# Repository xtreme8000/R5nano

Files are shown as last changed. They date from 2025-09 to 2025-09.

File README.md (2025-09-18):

# R5 nano

Single board computer with future Linux support, mostly intended for use as a lightweight server.

Planned SoC implementation using LiteX featuring a RISC-V CPU and 64MiB RAM.

## Gateware

TODO

## Software

Work in progress.

Firmware supports bitstream upload over USB to the FPGA at the moment.

## Hardware

* iCE40UP5k FPGA, 5280 LUTs
* 64MiB SD-RAM
* microSD card for storage
* USB port for connectivity like ethernet
* USB-C port for power, bitstream upload
* STM32F103 for initial bitstream load from either USB-C or microSD
* Debug header with FPGA+STM32 GPIO, SWD for STM32
* 52x52mm (~2x2in) board

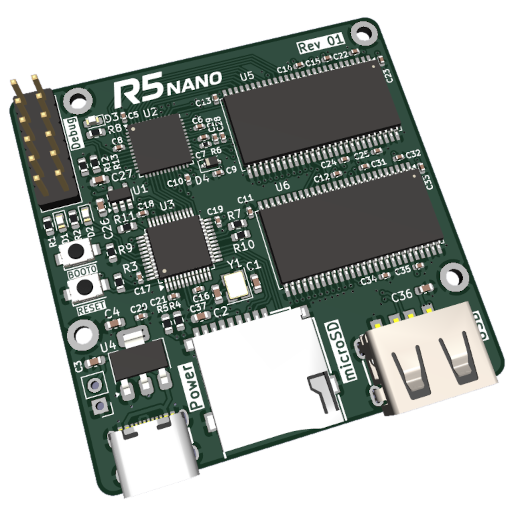
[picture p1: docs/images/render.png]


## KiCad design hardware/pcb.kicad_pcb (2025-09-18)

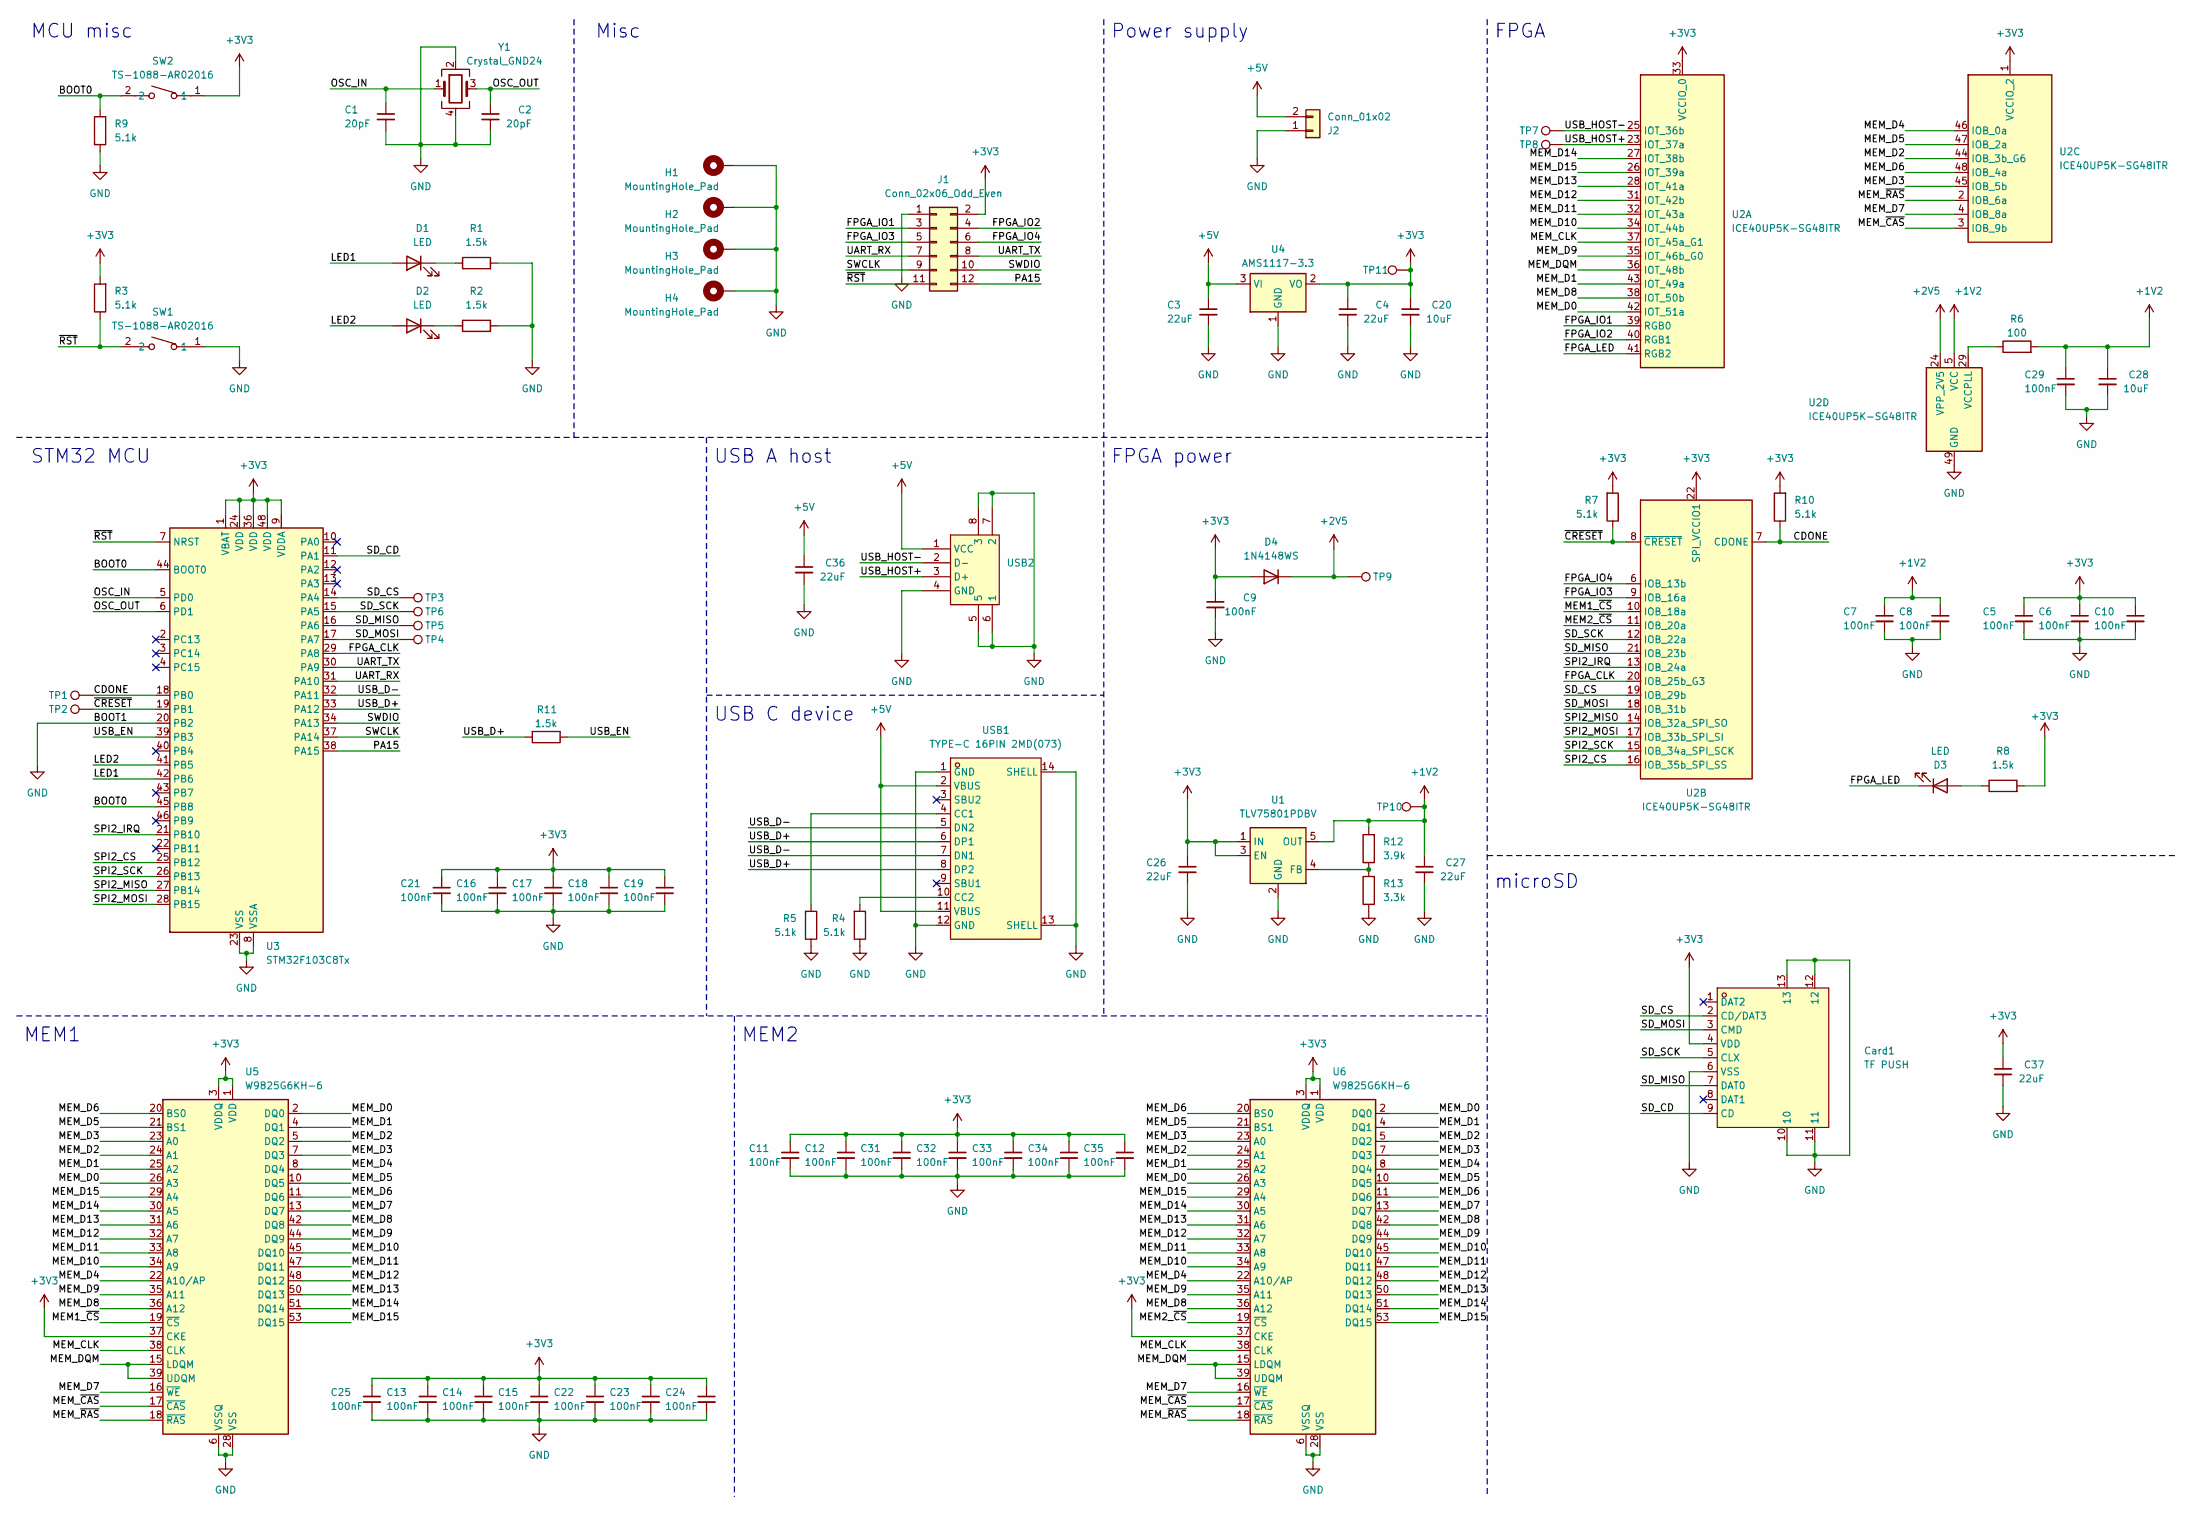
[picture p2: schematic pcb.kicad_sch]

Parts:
C1, C2: 20pF; C_0603_1608Metric; LCSC Part C1648
C3, C4, C26, C27, C36, C37: 22uF; C_0603_1608Metric; LCSC Part C59461
C5, C6, C7, C8, C9, C10, C11, C12, C13, C14, C15, C16, C17, C18, C19, C21, C22, C23, C24, C25, C29, C31, C32, C33, C34, C35: 100nF; C_0402_1005Metric; LCSC Part C1525
C20, C28: 10uF; C_0402_1005Metric; LCSC Part C15525
Card1: TF PUSH; TF-SMD_TF-PUSH; LCSC Part C393941
D1, D2, D3: LED; LED_0603_1608Metric; LCSC Part C2286
D4: 1N4148WS; D_SOD-323; LCSC Part C2128
H1, H2, H3, H4: MountingHole_Pad; MountingHole_2.2mm_M2_DIN965_Pad
J1: Conn_02x06_Odd_Even; PinHeader_2x06_P2.54mm_Vertical
J2: Conn_01x02; PinHeader_1x02_P2.54mm_Vertical
R1, R2, R8, R11: 1.5k; R_0603_1608Metric; LCSC Part C22843
R3, R4, R5, R7, R9, R10: 5.1k; R_0603_1608Metric; LCSC Part C23186
R6: 100; R_0402_1005Metric; LCSC Part C25076
R12: 3.9k; R_0603_1608Metric; LCSC Part C23018
R13: 3.3k; R_0603_1608Metric; LCSC Part C22978
SW1, SW2: TS-1088-AR02016; SW-SMD_L3.9-W3.0-P4.45; LCSC Part C720477
TP1, TP2, TP3, TP4, TP5, TP6, TP7, TP8, TP9, TP10, TP11: TestPoint; TestPoint_Pad_D2.0mm
U1: TLV75801PDBV; SOT-23-5; LCSC Part C2877852
U2: ICE40UP5K-SG48ITR; QFN-48-1EP_7x7mm_P0.5mm_EP5.6x5.6mm; LCSC Part C2678152
U3: STM32F103C8Tx; LQFP-48_7x7mm_P0.5mm; LCSC Part C8734
U4: AMS1117-3.3; SOT-223-3_TabPin2; LCSC Part C6186
U5, U6: W9825G6KH-6; TSOP-II-54_22.2x10.16mm_P0.8mm; LCSC Part C62246
USB1: TYPE-C 16PIN 2MD(073); USB-C-SMD_TYPE-C-6PIN-2MD-073; LCSC Part C2765186
USB2: USB-A-SMD_USB-M-21; LCSC Part C42474
Y1: Crystal_GND24; Crystal_SMD_3225-4Pin_3.2x2.5mm; LCSC Part C9002

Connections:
+1V2: C7.1, C8.1, C27.1, C28.1, C29.1, R6.2, R12.2, TP10.1, U1.5 (OUT), U2.5 (VCC), U2.30 (VCC)
+2V5: D4.1 (K), TP9.1, U2.24 (VPP_2V5)
+3V3: C4.1, C5.1, C6.1, C9.1, C10.1, C11.1, C12.1, C13.1, C14.1, C15.1, C16.1, C17.1, C18.1, C19.1, C20.1, C21.1, C22.1, C23.1, C24.1, C25.1, C26.1, C31.1, C32.1, C33.1, C34.1, C35.1, C37.1, Card1.4 (VDD), D4.2 (A), J1.2, R3.2, R7.2, R8.2, R10.2, SW2.1, TP11.1, U1.1 (IN), U1.3 (EN), U2.1 (VCCIO_2), U2.22 (SPI_VCCIO1), U2.33 (VCCIO_0), U3.1 (VBAT), U3.9 (VDDA), U3.24 (VDD), U3.36 (VDD), U3.48 (VDD), U4.2 (VO), U5.1 (VDD), U5.3 (VDDQ), U5.9 (VDDQ), U5.14 (VDD), U5.27 (VDD), U5.37 (CKE), U5.43 (VDDQ), U5.49 (VDDQ), U6.1 (VDD), U6.3 (VDDQ), U6.9 (VDDQ), U6.14 (VDD), U6.27 (VDD), U6.37 (CKE), U6.43 (VDDQ), U6.49 (VDDQ)
+5V: C3.1, C36.1, J2.2, U4.3 (VI), USB1.2 (VBUS), USB1.11 (VBUS), USB2.1 (VCC)
/BOOT0: R9.2, SW2.2, U3.44 (BOOT0), U3.45 (PB8)
/CDONE: R10.1, TP1.1, U2.7 (CDONE), U3.18 (PB0)
/FPGA_CLK: U2.20 (IOB_25b_G3), U3.29 (PA8)
/FPGA_IO1: J1.3, U2.39 (RGB0)
/FPGA_IO2: J1.4, U2.40 (RGB1)
/FPGA_IO3: J1.5, U2.9 (IOB_16a)
/FPGA_IO4: J1.6, U2.6 (IOB_13b)
/FPGA_LED: D3.1 (K), U2.41 (RGB2)
/LED1: D1.2 (A), U3.42 (PB6)
/LED2: D2.2 (A), U3.41 (PB5)
/MEM1_~CS: U2.10 (IOB_18a), U5.19 (~CS)
/MEM2_~CS: U2.11 (IOB_20a), U6.19 (~CS)
/MEM_CLK: U2.37 (IOT_45a_G1), U5.38 (CLK), U6.38 (CLK)
/MEM_D0: U2.42 (IOT_51a), U5.2 (DQ0), U5.26 (A3), U6.2 (DQ0), U6.26 (A3)
/MEM_D1: U2.43 (IOT_49a), U5.4 (DQ1), U5.25 (A2), U6.4 (DQ1), U6.25 (A2)
/MEM_D2: U2.44 (IOB_3b_G6), U5.5 (DQ2), U5.24 (A1), U6.5 (DQ2), U6.24 (A1)
/MEM_D3: U2.45 (IOB_5b), U5.7 (DQ3), U5.23 (A0), U6.7 (DQ3), U6.23 (A0)
/MEM_D4: U2.46 (IOB_0a), U5.8 (DQ4), U5.22 (A10/AP), U6.8 (DQ4), U6.22 (A10/AP)
/MEM_D5: U2.47 (IOB_2a), U5.10 (DQ5), U5.21 (BS1), U6.10 (DQ5), U6.21 (BS1)
/MEM_D6: U2.48 (IOB_4a), U5.11 (DQ6), U5.20 (BS0), U6.11 (DQ6), U6.20 (BS0)
/MEM_D7: U2.4 (IOB_8a), U5.13 (DQ7), U5.16 (~WE), U6.13 (DQ7), U6.16 (~WE)
/MEM_D8: U2.38 (IOT_50b), U5.36 (A12), U5.42 (DQ8), U6.36 (A12), U6.42 (DQ8)
/MEM_D9: U2.35 (IOT_46b_G0), U5.35 (A11), U5.44 (DQ9), U6.35 (A11), U6.44 (DQ9)
/MEM_D10: U2.34 (IOT_44b), U5.34 (A9), U5.45 (DQ10), U6.34 (A9), U6.45 (DQ10)
/MEM_D11: U2.32 (IOT_43a), U5.33 (A8), U5.47 (DQ11), U6.33 (A8), U6.47 (DQ11)
/MEM_D12: U2.31 (IOT_42b), U5.32 (A7), U5.48 (DQ12), U6.32 (A7), U6.48 (DQ12)
/MEM_D13: U2.28 (IOT_41a), U5.31 (A6), U5.50 (DQ13), U6.31 (A6), U6.50 (DQ13)
/MEM_D14: U2.27 (IOT_38b), U5.30 (A5), U5.51 (DQ14), U6.30 (A5), U6.51 (DQ14)
/MEM_D15: U2.26 (IOT_39a), U5.29 (A4), U5.53 (DQ15), U6.29 (A4), U6.53 (DQ15)
/MEM_DQM: U2.36 (IOT_48b), U5.15 (LDQM), U5.39 (UDQM), U6.15 (LDQM), U6.39 (UDQM)
/MEM_~CAS: U2.3 (IOB_9b), U5.17 (~CAS), U6.17 (~CAS)
/MEM_~RAS: U2.2 (IOB_6a), U5.18 (~RAS), U6.18 (~RAS)
/OSC_IN: C1.1, U3.5 (PD0), Y1.1
/OSC_OUT: C2.1, U3.6 (PD1), Y1.3
/PA15: J1.12, U3.38 (PA15)
/SD_CD: Card1.9 (CD), U3.11 (PA1)
/SD_CS: Card1.2 (CD/DAT3), TP3.1, U2.19 (IOB_29b), U3.14 (PA4)
/SD_MISO: Card1.7 (DAT0), TP5.1, U2.21 (IOB_23b), U3.16 (PA6)
/SD_MOSI: Card1.3 (CMD), TP4.1, U2.18 (IOB_31b), U3.17 (PA7)
/SD_SCK: Card1.5 (CLX), TP6.1, U2.12 (IOB_22a), U3.15 (PA5)
/SPI2_CS: U2.16 (IOB_35b_SPI_SS), U3.25 (PB12)
/SPI2_IRQ: U2.13 (IOB_24a), U3.21 (PB10)
/SPI2_MISO: U2.14 (IOB_32a_SPI_SO), U3.27 (PB14)
/SPI2_MOSI: U2.17 (IOB_33b_SPI_SI), U3.28 (PB15)
/SPI2_SCK: U2.15 (IOB_34a_SPI_SCK), U3.26 (PB13)
/SWCLK: J1.9, U3.37 (PA14)
/SWDIO: J1.10, U3.34 (PA13)
/UART_RX: J1.7, U3.31 (PA10)
/UART_TX: J1.8, U3.30 (PA9)
/USB_D+: R11.2, U3.33 (PA12), USB1.6 (DP1), USB1.8 (DP2)
/USB_D-: U3.32 (PA11), USB1.5 (DN2), USB1.7 (DN1)
/USB_EN: R11.1, U3.39 (PB3)
/USB_HOST+: TP8.1, U2.23 (IOT_37a), USB2.3 (D+)
/USB_HOST-: TP7.1, U2.25 (IOT_36b), USB2.2 (D-)
/~CRESET: R7.1, TP2.1, U2.8 (~CRESET), U3.19 (PB1)
/~RST: J1.11, R3.1, SW1.2, U3.7 (NRST)
GND: C1.2, C2.2, C3.2, C4.2, C5.2, C6.2, C7.2, C8.2, C9.2, C10.2, C11.2, C12.2, C13.2, C14.2, C15.2, C16.2, C17.2, C18.2, C19.2, C20.2, C21.2, C22.2, C23.2, C24.2, C25.2, C26.2, C27.2, C28.2, C29.2, C31.2, C32.2, C33.2, C34.2, C35.2, C36.2, C37.2, Card1.6 (VSS), Card1.10, Card1.11, Card1.12, Card1.13, H1.1, H2.1, H3.1, H4.1, J1.1, J2.1, R1.2, R2.2, R4.1, R5.1, R9.1, R13.1, SW1.1, U1.2 (GND), U2.49 (GND), U3.8 (VSSA), U3.20 (PB2), U3.23 (VSS), U3.35 (VSS), U3.47 (VSS), U4.1 (GND), U5.6 (VSSQ), U5.12 (VSSQ), U5.28 (VSS), U5.41 (VSS), U5.46 (VSSQ), U5.52 (VSSQ), U5.54 (VSS), U6.6 (VSSQ), U6.12 (VSSQ), U6.28 (VSS), U6.41 (VSS), U6.46 (VSSQ), U6.52 (VSSQ), U6.54 (VSS), USB1.1 (GND), USB1.12 (GND), USB1.13 (SHELL), USB1.14 (SHELL), USB2.4 (GND), USB2.5, USB2.6 (1), USB2.7 (2), USB2.8 (3), Y1.2, Y1.4
unnamed: D1.1 (K), R1.1
unnamed: D2.1 (K), R2.1
unnamed: D3.2 (A), R8.1
unnamed: R12.1, R13.2, U1.4 (FB)
unnamed: R6.1, U2.29 (VCCPLL)
unnamed: R5.2, USB1.4 (CC1)
unnamed: R4.2, USB1.10 (CC2)

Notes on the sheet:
microSD
MEM1
Misc
STM32 MCU
USB A host
MCU misc
MEM2
USB C device
Power supply
FPGA power
FPGA

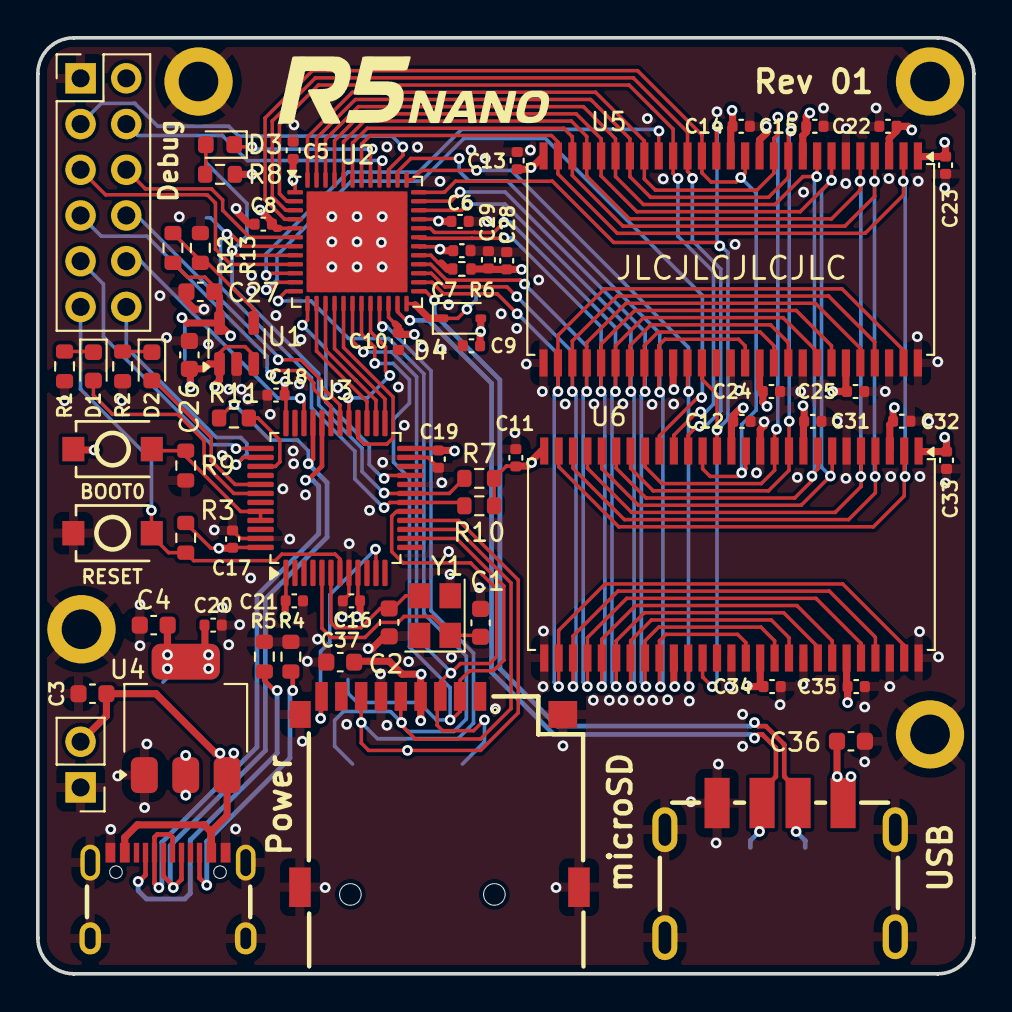
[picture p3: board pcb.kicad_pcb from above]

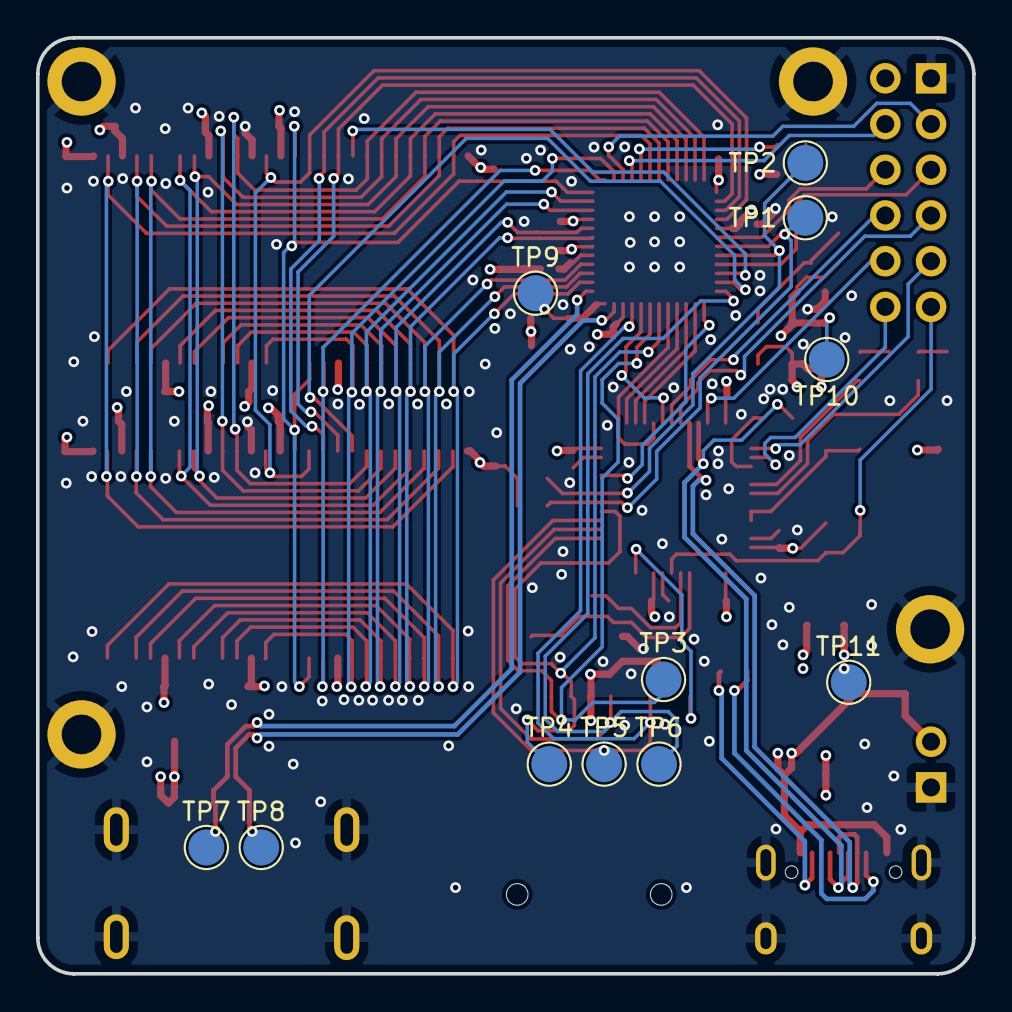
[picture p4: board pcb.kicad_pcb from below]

Board: 4 copper layers, 52.0 x 52.0 mm, 82 parts (11 on the bottom side), 68 nets.

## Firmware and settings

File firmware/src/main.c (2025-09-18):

#ifndef STM32F1
#define STM32F1
#endif

#include <stdio.h>
#include <stdlib.h>
#include <string.h>

#include <libopencm3/cm3/nvic.h>
#include <libopencm3/cm3/systick.h>
#include <libopencm3/stm32/dma.h>
#include <libopencm3/stm32/gpio.h>
#include <libopencm3/stm32/rcc.h>
#include <libopencm3/stm32/spi.h>
#include <libopencm3/stm32/usart.h>
#include <libopencm3/usb/usbd.h>

#include <FreeRTOS.h>
#include <queue.h>
#include <semphr.h>
#include <task.h>

#define PORT_CRESET_B GPIOB
#define PIN_CRESET_B GPIO1

#define PORT_SPI_SS GPIOB
#define PIN_SPI_SS GPIO12

#define PORT_CDONE GPIOB
#define PIN_CDONE GPIO0

#define PORT_USB_EN GPIOB
#define PIN_USB_EN GPIO3

#define PORT_LED1 GPIOB
#define PIN_LED1 GPIO6

#define PORT_LED2 GPIOB
#define PIN_LED2 GPIO5

uint8_t usbd_control_buffer[64]; // buffer for control requests

#define STREAM_PAYLOAD_DATA_SIZE 256

struct stream_payload {
	size_t length;
	uint8_t data[STREAM_PAYLOAD_DATA_SIZE];
};

struct usb_device_descriptor dev_descr = {
	.bLength = USB_DT_DEVICE_SIZE,
	.bDescriptorType = USB_DT_DEVICE,
	.bcdUSB = 0x0200,
	.bDeviceClass = 0,
	.bDeviceSubClass = 0,
	.bDeviceProtocol = 0,
	.bMaxPacketSize0 = 64, // max size
	.idVendor = 0x1209,
	.idProduct = 0x000E,
	.bcdDevice = 0x0100,
	.iManufacturer = 1,
	.iProduct = 2,
	.iSerialNumber = 0,
	.bNumConfigurations = 1,
};

struct usb_endpoint_descriptor usb_endpoints[] = {
	{
		.bLength = USB_DT_ENDPOINT_SIZE,
		.bDescriptorType = USB_DT_ENDPOINT,
		.bEndpointAddress = USB_ENDPOINT_ADDR_OUT(1),
		.bmAttributes = USB_ENDPOINT_ATTR_BULK,
		.wMaxPacketSize = STREAM_PAYLOAD_DATA_SIZE,
	},
	{
		.bLength = USB_DT_ENDPOINT_SIZE,
		.bDescriptorType = USB_DT_ENDPOINT,
		.bEndpointAddress = USB_ENDPOINT_ADDR_IN(2),
		.bmAttributes = USB_ENDPOINT_ATTR_INTERRUPT,
		.wMaxPacketSize = 1,
		.bInterval = 5,
	},
};

struct usb_interface_descriptor usb_iface = {
	.bLength = USB_DT_INTERFACE_SIZE,
	.bDescriptorType = USB_DT_INTERFACE,
	.bInterfaceNumber = 0,
	.bAlternateSetting = 0,
	.bNumEndpoints = 2,
	.bInterfaceClass = USB_CLASS_VENDOR,
	.bInterfaceSubClass = 0,
	.bInterfaceProtocol = 0,
	.iInterface = 0,
	.endpoint = usb_endpoints,
};

struct usb_config_descriptor usb_config = {
	.bLength = USB_DT_CONFIGURATION_SIZE,
	.bDescriptorType = USB_DT_CONFIGURATION,
	.wTotalLength = 0,
	.bNumInterfaces = 1,
	.bConfigurationValue = 1,
	.iConfiguration = 0,
	.bmAttributes = USB_CONFIG_ATTR_DEFAULT,
	.bMaxPower = 100 / 2, // 100mA

	.interface = (struct usb_interface[]) {{
		.num_altsetting = 1,
		.altsetting = &usb_iface,
	}},
};

const char* usb_strings[3] = {
	"xtreme8000",
	"R5nano",
};

QueueHandle_t incoming_data;
QueueHandle_t available_buffers;
QueueHandle_t usb_host_interrupt;

void usb_endpoint_callback(usbd_device* dev, uint8_t ep) {
	if(ep != USB_ENDPOINT_ADDR_OUT(1))
		return;

	struct stream_payload* e;
	xQueueReceive(available_buffers, &e, portMAX_DELAY);
	e->length = usbd_ep_read_packet(dev, ep, e->data, sizeof(e->data));
	xQueueSend(incoming_data, &e, portMAX_DELAY);
}

enum usbd_request_return_codes
usb_creq_callback(usbd_device* dev, struct usb_setup_data* req, uint8_t** buf,
				  uint16_t* len,
				  void (**complete)(usbd_device*, struct usb_setup_data*)) {
	if(req->bmRequestType
	   != (USB_REQ_TYPE_OUT | USB_REQ_TYPE_VENDOR | USB_REQ_TYPE_INTERFACE))
		return USBD_REQ_NOTSUPP;

	switch(req->bRequest) {
		case 10:
			if(req->wLength != 4)
				return USBD_REQ_NOTSUPP;

			uint32_t payload_length = ((*buf)[3] << 24) | ((*buf)[2] << 16)
				| ((*buf)[1] << 8) | (*buf)[0];

			struct stream_payload* e;
			xQueueReceive(available_buffers, &e, portMAX_DELAY);
			e->length = payload_length;
			xQueueSend(incoming_data, &e, portMAX_DELAY);

			return USBD_REQ_HANDLED;
		default: return USBD_REQ_NOTSUPP;
	}
}

static void usb_set_config(usbd_device* dev, uint16_t wValue) {
	usbd_register_control_callback(
		dev, USB_REQ_TYPE_VENDOR | USB_REQ_TYPE_INTERFACE,
		USB_REQ_TYPE_TYPE | USB_REQ_TYPE_RECIPIENT, usb_creq_callback);
	usbd_ep_setup(dev, USB_ENDPOINT_ADDR_OUT(1), USB_ENDPOINT_ATTR_BULK,
				  STREAM_PAYLOAD_DATA_SIZE, usb_endpoint_callback);
	usbd_ep_setup(dev, USB_ENDPOINT_ADDR_IN(2), USB_ENDPOINT_ATTR_INTERRUPT, 1,
				  NULL);
}

void task_usb(void* args) {
	gpio_clear(PORT_USB_EN, PIN_USB_EN);
	vTaskDelay(pdMS_TO_TICKS(100));
	gpio_set(PORT_USB_EN, PIN_USB_EN);

	usbd_device* usbd_dev = usbd_init(
		&st_usbfs_v1_usb_driver, &dev_descr, &usb_config, usb_strings, 2,
		usbd_control_buffer, sizeof(usbd_control_buffer));
	usbd_register_set_config_callback(usbd_dev, usb_set_config);

	while(1) {
		usbd_poll(usbd_dev);

		uint8_t signal;
		if(xQueueReceive(usb_host_interrupt, &signal, 0)) {
			// raise host interrupt
			usbd_ep_write_packet(usbd_dev, USB_ENDPOINT_ADDR_IN(2), &signal,
								 sizeof(signal));
		}
	}
}

void task_blink(void* args) {
	while(1) {
		gpio_toggle(PORT_LED1, PIN_LED1);
		vTaskDelay(pdMS_TO_TICKS(500));
	}
}

TaskHandle_t task_upload_handle;

struct stream_payload* payload_current = NULL;
uint32_t payload_total = 0;
uint32_t payload_transmitted = 0;

void dma1_channel5_isr(void) {
	dma_disable_channel(DMA1, DMA_CHANNEL5);
	dma_clear_interrupt_flags(DMA1, DMA_CHANNEL5, DMA_TCIF);

	BaseType_t task_woken = pdFALSE;

	struct stream_payload* e;
	if(payload_transmitted < payload_total
	   && xQueueReceiveFromISR(incoming_data, &e, &task_woken)) {
		dma_set_memory_address(DMA1, DMA_CHANNEL5, (uint32_t)e->data);
		dma_set_number_of_data(DMA1, DMA_CHANNEL5, e->length);
		dma_enable_channel(DMA1, DMA_CHANNEL5);
	} else {
		e = NULL;
		vTaskNotifyGiveFromISR(task_upload_handle, &task_woken);
	}

	if(payload_current) {
		payload_transmitted += payload_current->length;
		xQueueSendFromISR(available_buffers, &payload_current, &task_woken);
	}

	payload_current = e;
	portYIELD_FROM_ISR(task_woken);
}

void spi_wait_idle(uint32_t spi) {
	while(SPI_SR(spi) & SPI_SR_BSY)
		;
}

void task_upload(void* args) {
	while(1) {
		struct stream_payload* e;
		xQueueReceive(incoming_data, &e, portMAX_DELAY);
		payload_total = e->length;
		payload_transmitted = 0;
		xQueueSend(available_buffers, &e, portMAX_DELAY);

		gpio_set(PORT_LED2, PIN_LED2);

		gpio_clear(PORT_CRESET_B, PIN_CRESET_B);
		gpio_clear(PORT_SPI_SS, PIN_SPI_SS);
		// clear cresetb for 1-2ms
		vTaskDelay(pdMS_TO_TICKS(2));
		gpio_set(PORT_CRESET_B, PIN_CRESET_B);
		// clear spi_ss for 2-3ms
		vTaskDelay(pdMS_TO_TICKS(3));
		gpio_set(PORT_SPI_SS, PIN_SPI_SS);
		// generate 8 clock cycles
		spi_send(SPI2, 0);
		spi_wait_idle(SPI2);
		gpio_clear(PORT_SPI_SS, PIN_SPI_SS);

		// TODO: error handling, e.g. stream ends early

		while(payload_transmitted < payload_total) {
			xQueueReceive(incoming_data, &e, portMAX_DELAY);
			payload_current = e;
			dma_set_memory_address(DMA1, DMA_CHANNEL5, (uint32_t)e->data);
			dma_set_number_of_data(DMA1, DMA_CHANNEL5, e->length);
			dma_enable_channel(DMA1, DMA_CHANNEL5);
			ulTaskNotifyTake(pdTRUE, portMAX_DELAY);
		}

		spi_wait_idle(SPI2);
		gpio_set(PORT_SPI_SS, PIN_SPI_SS);

		for(size_t k = 0; k < 20; k++)
			spi_send(SPI2, k);

		spi_wait_idle(SPI2);

		uint8_t success = gpio_get(PORT_CDONE, PIN_CDONE) ? 1 : 0;
		xQueueSend(usb_host_interrupt, &success, portMAX_DELAY);

		gpio_clear(PORT_LED2, PIN_LED2);
	}
}

int main() {
	rcc_clock_setup_pll(rcc_hse_configs + RCC_CLOCK_HSE12_72MHZ);

	rcc_periph_clock_enable(RCC_USART1);
	rcc_periph_clock_enable(RCC_AFIO);
	rcc_periph_clock_enable(RCC_GPIOA);
	rcc_periph_clock_enable(RCC_GPIOB);
	rcc_periph_clock_enable(RCC_GPIOC);

	gpio_primary_remap(AFIO_MAPR_SWJ_CFG_JTAG_OFF_SW_ON, 0);

	gpio_set_mode(GPIOA, GPIO_MODE_OUTPUT_50_MHZ,
				  GPIO_CNF_OUTPUT_ALTFN_PUSHPULL, GPIO8);
	rcc_set_mco(RCC_CFGR_MCO_HSE);

	gpio_set_mode(GPIO_BANK_USART1_TX, GPIO_MODE_OUTPUT_50_MHZ,
				  GPIO_CNF_OUTPUT_ALTFN_PUSHPULL, GPIO_USART1_TX);

	usart_set_baudrate(USART1, 115200);
	usart_set_databits(USART1, 8);
	usart_set_stopbits(USART1, USART_STOPBITS_1);
	usart_set_parity(USART1, USART_PARITY_NONE);
	usart_set_flow_control(USART1, USART_FLOWCONTROL_NONE);
	usart_set_mode(USART1, USART_MODE_TX);
	usart_enable(USART1);

	// usb setup
	gpio_set_mode(PORT_USB_EN, GPIO_MODE_OUTPUT_2_MHZ, GPIO_CNF_OUTPUT_PUSHPULL,
				  PIN_USB_EN);
	gpio_clear(PORT_USB_EN, PIN_USB_EN);

	// blink setup
	gpio_set_mode(PORT_LED1, GPIO_MODE_OUTPUT_2_MHZ, GPIO_CNF_OUTPUT_PUSHPULL,
				  PIN_LED1);
	gpio_clear(PORT_LED1, PIN_LED1);
	gpio_set_mode(PORT_LED2, GPIO_MODE_OUTPUT_2_MHZ, GPIO_CNF_OUTPUT_PUSHPULL,
				  PIN_LED2);
	gpio_clear(PORT_LED2, PIN_LED2);

	// upload setup
	rcc_periph_clock_enable(RCC_SPI2);
	rcc_periph_clock_enable(RCC_DMA1);

	gpio_set_mode(GPIO_BANK_SPI2_SCK, GPIO_MODE_OUTPUT_50_MHZ,
				  GPIO_CNF_OUTPUT_ALTFN_PUSHPULL, GPIO_SPI2_SCK);
	gpio_set_mode(GPIO_BANK_SPI2_MOSI, GPIO_MODE_OUTPUT_50_MHZ,
				  GPIO_CNF_OUTPUT_ALTFN_PUSHPULL, GPIO_SPI2_MOSI);
	gpio_set_mode(GPIO_BANK_SPI2_MISO, GPIO_MODE_INPUT, GPIO_CNF_INPUT_FLOAT,
				  GPIO_SPI2_MISO);

	spi_init_master(
		SPI2, SPI_CR1_BAUDRATE_FPCLK_DIV_32, SPI_CR1_CPOL_CLK_TO_1_WHEN_IDLE,
		SPI_CR1_CPHA_CLK_TRANSITION_2, SPI_CR1_DFF_8BIT, SPI_CR1_MSBFIRST);
	spi_enable_software_slave_management(SPI2);
	spi_set_nss_high(SPI2);
	spi_enable_tx_dma(SPI2);
	spi_enable(SPI2);

	dma_channel_reset(DMA1, DMA_CHANNEL5);
	dma_set_memory_size(DMA1, DMA_CHANNEL5, DMA_CCR_MSIZE_8BIT);
	dma_set_peripheral_size(DMA1, DMA_CHANNEL5, DMA_CCR_PSIZE_8BIT);
	dma_set_peripheral_address(DMA1, DMA_CHANNEL5, (uint32_t)&SPI2_DR);
	dma_enable_memory_increment_mode(DMA1, DMA_CHANNEL5);
	dma_disable_peripheral_increment_mode(DMA1, DMA_CHANNEL5);
	dma_set_read_from_memory(DMA1, DMA_CHANNEL5);

	dma_enable_transfer_complete_interrupt(DMA1, DMA_CHANNEL5);
	nvic_set_priority(NVIC_DMA1_CHANNEL5_IRQ, 0);
	nvic_enable_irq(NVIC_DMA1_CHANNEL5_IRQ);

	gpio_set_mode(PORT_CRESET_B, GPIO_MODE_OUTPUT_50_MHZ,
				  GPIO_CNF_OUTPUT_PUSHPULL, PIN_CRESET_B);
	gpio_set_mode(PORT_SPI_SS, GPIO_MODE_OUTPUT_50_MHZ,
				  GPIO_CNF_OUTPUT_PUSHPULL, PIN_SPI_SS);
	gpio_set_mode(PORT_CDONE, GPIO_MODE_INPUT, GPIO_CNF_INPUT_FLOAT, PIN_CDONE);
	gpio_set(PORT_CRESET_B, PIN_CRESET_B);
	gpio_set(PORT_SPI_SS, PIN_SPI_SS);

	available_buffers = xQueueCreate(8, sizeof(struct stream_payload*));
	incoming_data = xQueueCreate(8, sizeof(struct stream_payload*));
	usb_host_interrupt = xQueueCreate(8, sizeof(uint8_t));

	for(size_t k = 0; k < 8; k++) {
		struct stream_payload* e = pvPortMalloc(sizeof(struct stream_payload));
		xQueueSend(available_buffers, &e, portMAX_DELAY);
	}

	xTaskCreate(task_upload, "upload", configMINIMAL_STACK_SIZE, NULL, 4,
				&task_upload_handle);
	xTaskCreate(task_usb, "usb", configMINIMAL_STACK_SIZE, NULL, 2, NULL);
	xTaskCreate(task_blink, "blink", configMINIMAL_STACK_SIZE, NULL, 3, NULL);
	vTaskStartScheduler();

	return 0;
}

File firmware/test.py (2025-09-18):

import usb.core
import usb.util
import struct
import argparse
import time

parser = argparse.ArgumentParser()
parser.add_argument('filename')
args = parser.parse_args()

with open(args.filename, "rb") as f:
    payload = f.read()

print(f"Uploading {len(payload)} bytes")

dev = usb.core.find(idVendor=0x1209, idProduct=0x000E)

if dev is None:
    raise ValueError('Device not found')

dev.set_configuration()
req = usb.util.build_request_type(usb.util.CTRL_OUT, usb.util.CTRL_TYPE_VENDOR, usb.util.CTRL_RECIPIENT_INTERFACE)

s1 = time.time()
dev.ctrl_transfer(req, 10, 0, 0, struct.pack('<l', len(payload)))
dev.write(0x01, payload)
status = dev.read(0x82, 1, 5000)[0] # wait for interrupt
s2 = time.time()

if status == 1:
	print(f"Successful! took {(s2 - s1) * 1000:.0f} ms")
else:
	print("Error! FPGA did not accept configuration")
